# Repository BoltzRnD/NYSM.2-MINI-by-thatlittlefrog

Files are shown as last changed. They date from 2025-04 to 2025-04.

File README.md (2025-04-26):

# NYSM.2-MINI

NYSM.2 compatible full featured TMC2209 stepper driver with a smaller footprint than standard NYSM.2


It's around half the size of the original NYSM.2 driver, occupying a "2215" footprint rather than 2230, the smallest size seen on commercial M.2 drives.

### Future versions: 
* Cleaner routing
* Better thermals
* Custom low profile heatsink
* Onboard setting jumpers for microstepping

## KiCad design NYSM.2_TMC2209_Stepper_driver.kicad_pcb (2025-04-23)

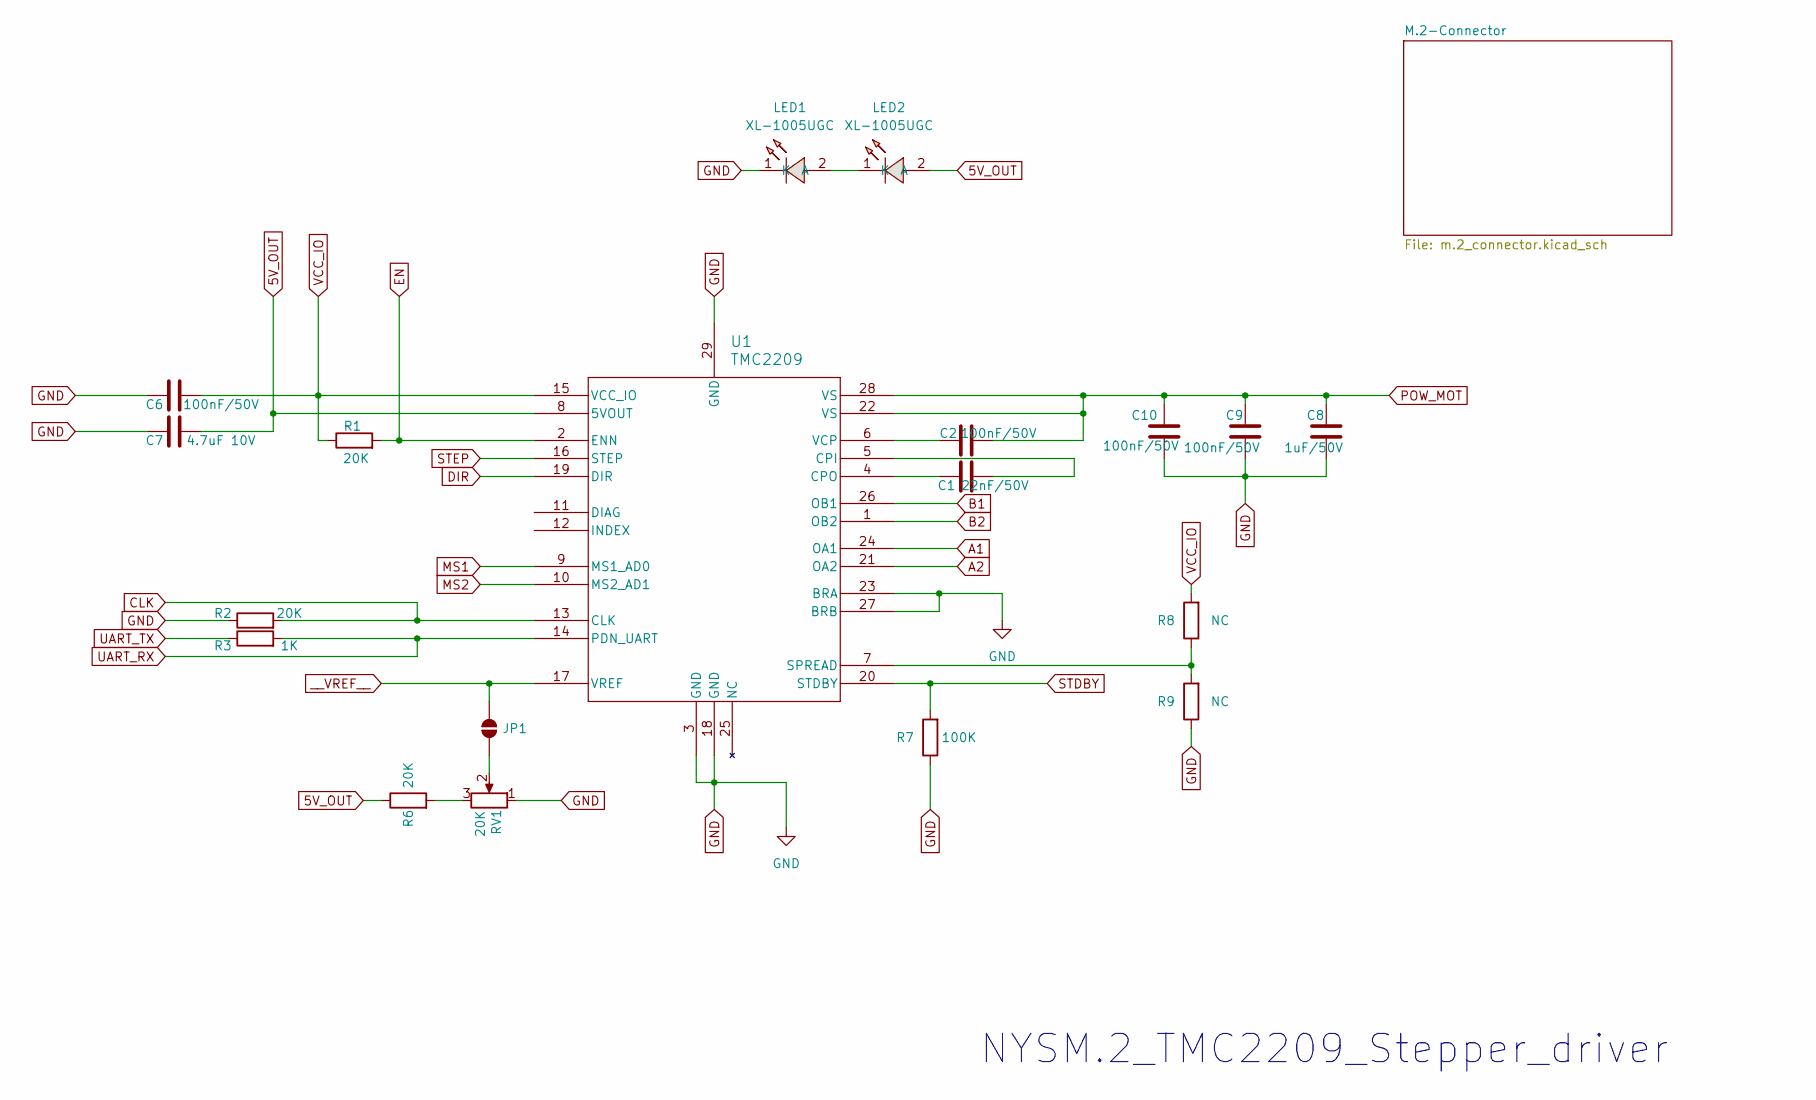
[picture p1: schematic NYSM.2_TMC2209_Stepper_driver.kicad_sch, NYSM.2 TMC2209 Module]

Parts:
C1: 22nF/50V; C_0402_1005Metric; Manufacturer_Part_Number CC0402KRX7R9BB223; LCSC# C107026
C2, C6, C9, C10: 100nF/50V; C_0402_1005Metric; Manufacturer_Part_Number 0402B104K500CT; LCSC# C152814
C7: 4.7uF 10V; C_0402_1005Metric; Manufacturer_Part_Number CL05A475KP5NRNC; LCSC# C368809
C8: 1uF/50V; C_0402_1005Metric; Manufacturer_Part_Number GRM155R61H105KE05D; LCSC# C1518208
JP1: SolderJumper-2_P1.3mm_Open_Pad1.0x1.5mm
LED1, LED2: XL-1005UGC; LED0402-RD_GREEN; LCSC Part C965793
R1, R2, R6: 20K; R_0402_1005Metric; Manufacturer_Part_Number WR04X203JTL; LCSC# C384364
R3: 1K; R_0402_1005Metric; Manufacturer_Part_Number WR04X1001FTL; LCSC# C163815
R7: 100K; R_0402_1005Metric; Manufacturer_Part_Number WR04X104JTL; LCSC# C384388
R8, R9: NC; R_0402_1005Metric
RV1: 20K; Potentiometer_Bourns_TC33X_Vertical; Manufacturer_Part_Number VG039NCHXTB203; LCSC# C128550
U1: TMC2209; QFN28_5X5_TRI; Manufacturer_Part_Number TMC2209; LCSC# C465949

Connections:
5V_OUT: C7.2, LED2.2 (A), R6.1, U1.8 (5VOUT)
A1: U1.24 (OA1); also elsewhere on the board
A2: U1.21 (OA2); also elsewhere on the board
B1: U1.26 (OB1); also elsewhere on the board
B2: U1.1 (OB2); also elsewhere on the board
CLK: R2.2, U1.13 (CLK); also elsewhere on the board
DIR: U1.19 (DIR); also elsewhere on the board
EN: R1.2, U1.2 (ENN); also elsewhere on the board
GND: C6.1, C7.1, C8.2, C9.2, C10.2, LED1.1 (K), R2.1, R7.1, R9.1, RV1.1, U1.3 (GND), U1.18 (GND), U1.23 (BRA), U1.27 (BRB), U1.29 (GND); also elsewhere on the board
MS1: U1.9 (MS1_AD0); also elsewhere on the board
MS2: U1.10 (MS2_AD1); also elsewhere on the board
unnamed: JP1.1 (A), RV1.2
unnamed: LED1.2 (A), LED2.1 (K)
unnamed: R6.2, RV1.3
unnamed: C1.2, U1.5 (CPI)
unnamed: C1.1, U1.4 (CPO)
unnamed: R8.1, R9.2, U1.7 (SPREAD)
unnamed: C2.1, U1.6 (VCP)
POW_MOT: C2.2, C8.1, C9.1, C10.1, U1.22 (VS), U1.28 (VS); also elsewhere on the board
STDBY: R7.2, U1.20 (STDBY); also elsewhere on the board
STEP: U1.16 (STEP); also elsewhere on the board
UART_RX: R3.2, U1.14 (PDN_UART); also elsewhere on the board
UART_TX: R3.1; also elsewhere on the board
VCC_IO: C6.2, R1.1, R8.2, U1.15 (VCC_IO); also elsewhere on the board
__VREF__: JP1.2 (B), U1.17 (VREF); also elsewhere on the board

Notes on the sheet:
NYSM.2_TMC2209_Stepper_driver

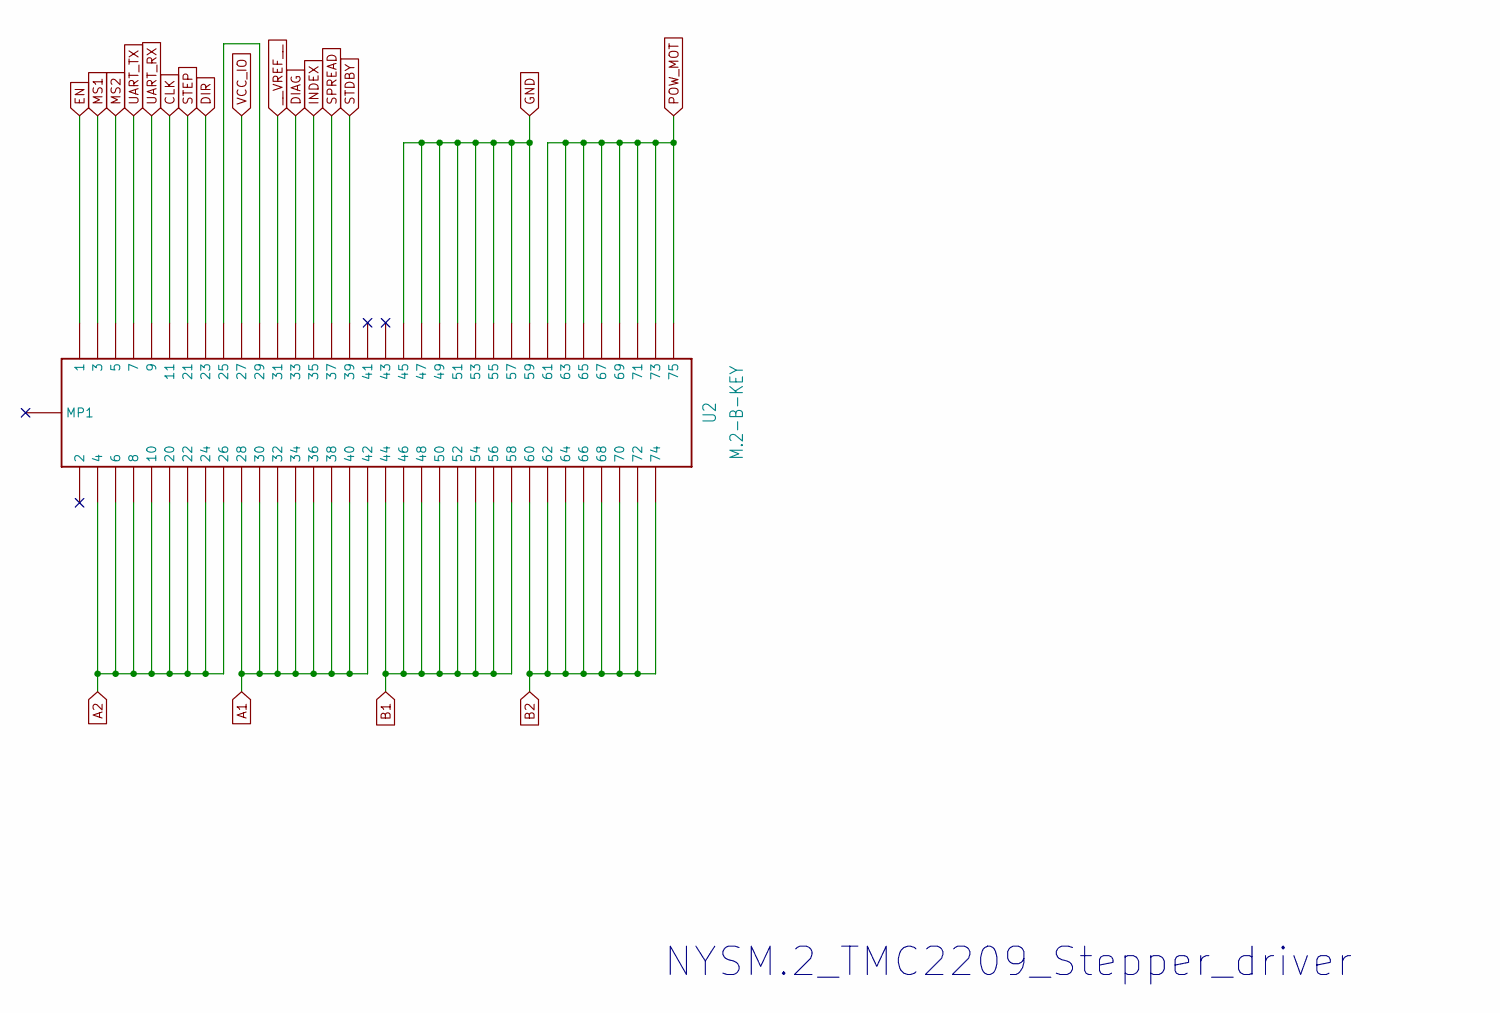
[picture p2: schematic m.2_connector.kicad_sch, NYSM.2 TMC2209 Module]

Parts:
U2: M.2-B-KEY; NYSM2-Card-B-Key

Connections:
A1: U2.P$28 (28), U2.P$30 (30), U2.P$32 (32), U2.P$34 (34), U2.P$36 (36), U2.P$38 (38), U2.P$40 (40), U2.P$42 (42); also elsewhere on the board
A2: U2.P$4 (4), U2.P$6 (6), U2.P$8 (8), U2.P$10 (10), U2.P$20 (20), U2.P$22 (22), U2.P$24 (24), U2.P$26 (26); also elsewhere on the board
B1: U2.P$44 (44), U2.P$46 (46), U2.P$48 (48), U2.P$50 (50), U2.P$52 (52), U2.P$54 (54), U2.P$56 (56), U2.P$58 (58); also elsewhere on the board
B2: U2.P$60 (60), U2.P$62 (62), U2.P$64 (64), U2.P$66 (66), U2.P$68 (68), U2.P$70 (70), U2.P$72 (72), U2.P$74 (74); also elsewhere on the board
CLK: U2.P$11 (11); also elsewhere on the board
DIAG: U2.P$33 (33)
DIR: U2.P$23 (23); also elsewhere on the board
EN: U2.P$1 (1); also elsewhere on the board
GND: U2.P$45 (45), U2.P$47 (47), U2.P$49 (49), U2.P$51 (51), U2.P$53 (53), U2.P$55 (55), U2.P$57 (57), U2.P$59 (59); also elsewhere on the board
INDEX: U2.P$35 (35)
MS1: U2.P$3 (3); also elsewhere on the board
MS2: U2.P$5 (5); also elsewhere on the board
unnamed: U2.P$25 (25), U2.P$29 (29)
POW_MOT: U2.P$61 (61), U2.P$63 (63), U2.P$65 (65), U2.P$67 (67), U2.P$69 (69), U2.P$71 (71), U2.P$73 (73), U2.P$75 (75); also elsewhere on the board
SPREAD: U2.P$37 (37)
STDBY: U2.P$39 (39); also elsewhere on the board
STEP: U2.P$21 (21); also elsewhere on the board
UART_RX: U2.P$9 (9); also elsewhere on the board
UART_TX: U2.P$7 (7); also elsewhere on the board
VCC_IO: U2.P$27 (27); also elsewhere on the board
__VREF__: U2.P$31 (31); also elsewhere on the board

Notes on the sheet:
NYSM.2_TMC2209_Stepper_driver

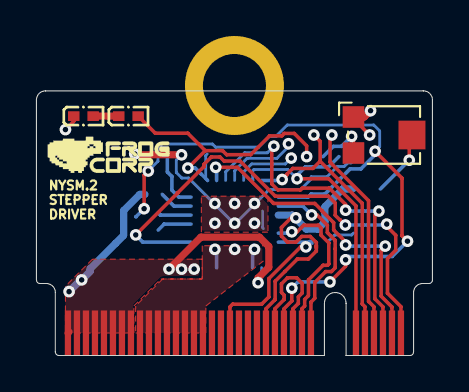
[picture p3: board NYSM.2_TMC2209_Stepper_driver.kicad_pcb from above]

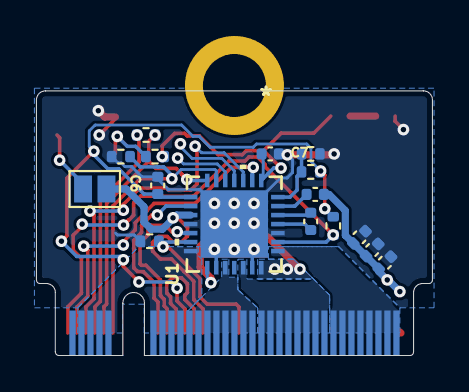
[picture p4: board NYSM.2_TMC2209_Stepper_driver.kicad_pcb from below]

Board: 2 copper layers, 22.0 x 14.7 mm, 20 parts (16 on the bottom side), 26 nets.

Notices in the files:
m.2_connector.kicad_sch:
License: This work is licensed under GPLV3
